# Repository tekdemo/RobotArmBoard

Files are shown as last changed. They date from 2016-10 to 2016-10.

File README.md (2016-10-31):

# Robot Arm Control Board

Teensy based control board designed for adding closed loop control to OWI-535 Robotic Arm Edge kit. 

## Setup

### Power
Using the 6 D cell battery output is suggested. See assembly notes for more details.

The Teensy is not powered by the batteries, and must be provided USB power for the robot to operate. 

### Motors

Each motor is driven by a pair of signal pins signals from the Teensy. Setting one `HIGH` and the other `LOW` will result in moving the motor, and thus each joint. 

- Pins `10` and `9` control `M1`, opening and closing the claw.
- Pins `6` and `5` control `M2`, the "wrist" joint
- Pins `4` and `3` control `M3`, the "elbow" joint. 
- Pins `20` and `21` control `M4`, the "shoulder" joint. 
- Pins `22` and `23` control `M5`, which rotates the arm 
- Pin `13` controls the light on the claw end. This is the same as the Teensy's built in LED.

### Analog Feedback

For closed loop feedback, the following pins are available:
- Pin `A1` corresponds to `M1`'s potentiometer. 
- Pin `A2` corresponds to `M2`'s potentiometer. 
- Pin `A3` corresponds to `M3`'s potentiometer. 
- Pin `A4` corresponds to `M4`'s potentiometer. 
- Pin `A5` corresponds to `M5`'s potentiometer. 

Note, each potentiometer "tuning" will be somewhat different, and require some setup for each robot and each joint. 

### Controller Input
The controller uses the same analog pins as the Analog feedback. As a result, it's not simple to use the controller for input when the analog feedback is plugged in. However, doing so will not harm the electronics. 

- Pin `A1` corresponds to `M1`'s joystick. 
- Pin `A2` corresponds to `M2`'s joystick. 
- Pin `A3` corresponds to `M3`'s joystick. 
- Pin `A4` corresponds to `M4`'s joystick. 
- Pin `A5` corresponds to `M5`'s joystick. 
- Pin `A0` corresponds to the Light slider. 

Due to the joystick construction the joystick will only generate a few values. When read using `AnalogRead`, you will get roughly `512` when the joystick is idle, and around `1023` or `0` when the joystick is pressed. 

The LED switch is wired up to it's own unique input, and can be used alongside a closed loop input without issue. The `LED` switch will be around `512` when off, and `1023` when on.

## Assembly

### Power Input

### Motors

### Controller Input Section

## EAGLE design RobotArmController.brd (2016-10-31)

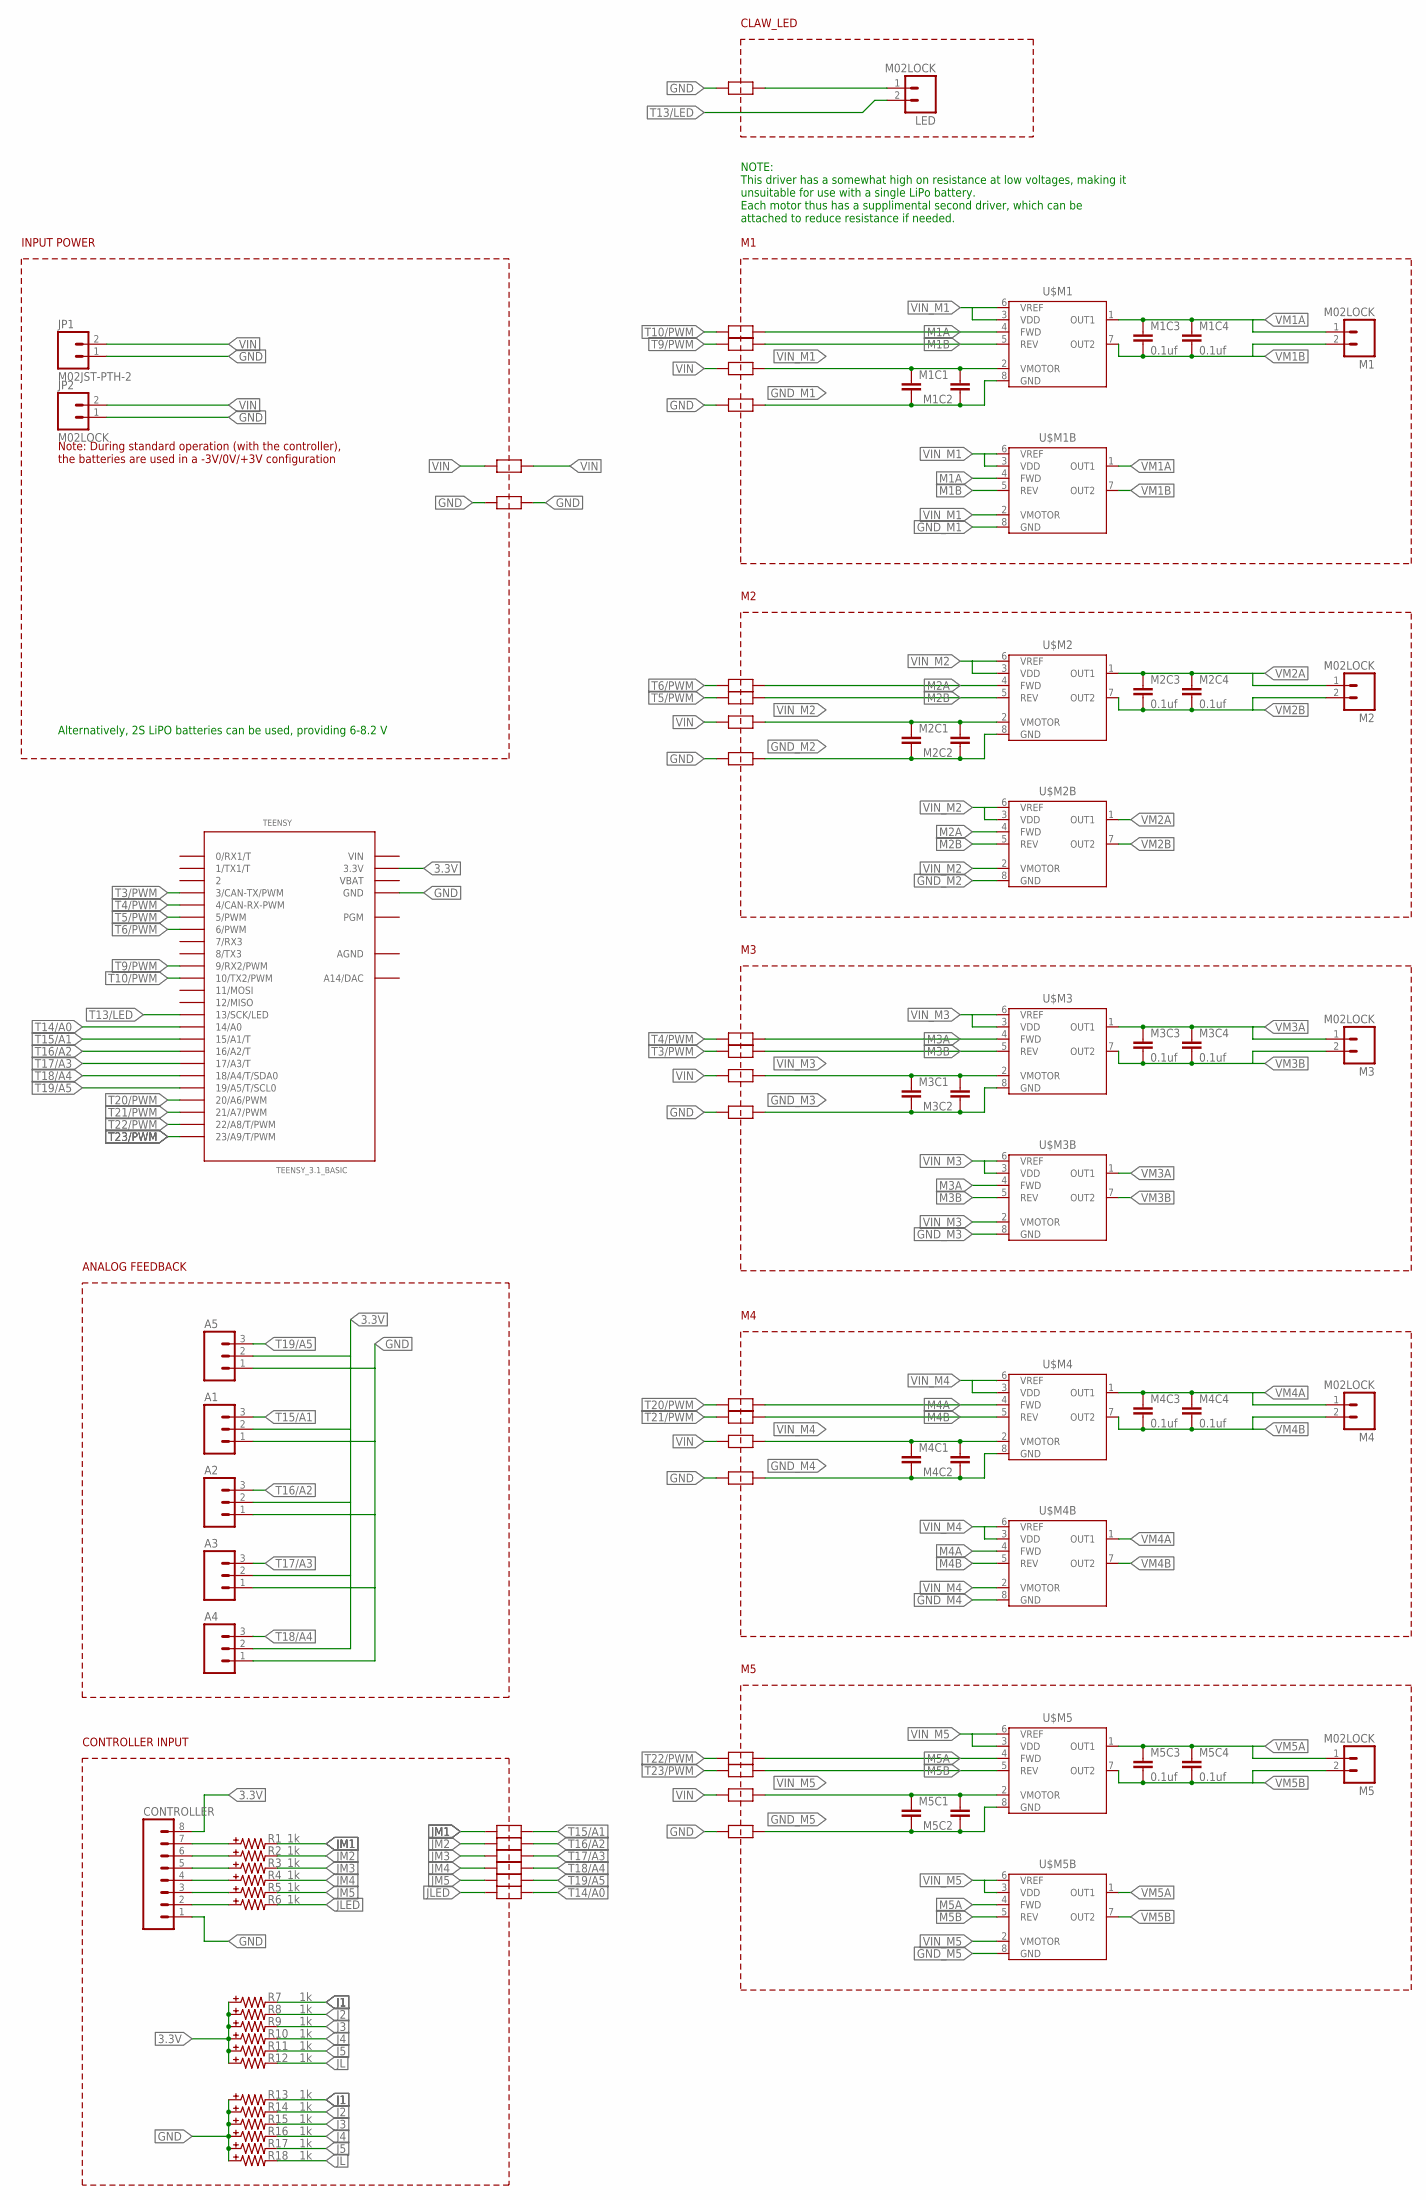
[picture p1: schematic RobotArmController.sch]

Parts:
A1, A2, A3, A4, A5: M03LOCK; 1X03_LOCK
CONTROLLER: M08LOCK; 1X08_LOCK
JP1: M02JST-PTH-2; JST-2-PTH
JP2: M02LOCK; 1X02_LOCK
LED: M02LOCK; 1X02_LOCK
M1, M2, M3, M4, M5: M02LOCK; 1X02_LOCK
M1C1, M2C1, M3C1, M4C1, M5C1: CAP1210; 1210
M1C2, M2C2, M3C2, M4C2, M5C2: CAPUNIVERSAL; 0402-0603-0805-UNIVERSAL
M1C3, M1C4, M2C3, M2C4, M3C3, M3C4, M4C3, M4C4, M5C3, M5C4: 0.1uf; 0402-0603-0805-UNIVERSAL
R1, R2, R3, R4, R5, R6, R7, R8, R9, R10, R11, R12, R13, R14, R15, R16, R17, R18: 1k; 0402-0603-0805-UNIVERSAL
TEENSY: TEENSY_3.1_BASIC
U$1, U$2, U$3, U$4, U$5, U$6, U$7, U$8, U$9, U$10, U$11, U$12, U$13, U$14, U$15, U$16, U$17, U$18, U$19, U$20, U$21, U$22, U$23, U$24, U$25, U$26, U$27, U$28, U$29: NET-JUNCTION-2
U$M1, U$M1B, U$M2, U$M2B, U$M3, U$M3B, U$M4, U$M4B, U$M5, U$M5B: ZXBM5210; SO08

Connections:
3.3V: A1.2, A2.2, A3.2, A4.2, A5.2, CONTROLLER.8, R7.+ (1), R8.+ (1), R9.+ (1), R10.+ (1), R11.+ (1), R12.+ (1), TEENSY.3.3V, TEENSY.3.3V1 (3.3V)
AGND: TEENSY.AGND
GND: A1.1, A2.1, A3.1, A4.1, A5.1, CONTROLLER.1, JP1.1, JP2.1, LED.1, R13.+ (1), R14.+ (1), R15.+ (1), R16.+ (1), R17.+ (1), R18.+ (1), TEENSY.GND, TEENSY.GND1 (GND), U$2.P$1, U$5.P$1, U$7.P$1, U$9.P$1, U$11.P$1, U$13.P$1, U$13.P$2, U$24.P$1, U$24.P$2
GND_M1: M1C1.2, M1C2.- (1), U$2.P$2, U$M1.8 (GND), U$M1B.8 (GND)
GND_M2: M2C1.2, M2C2.- (1), U$5.P$2, U$M2.8 (GND), U$M2B.8 (GND)
GND_M3: M3C1.2, M3C2.- (1), U$7.P$2, U$M3.8 (GND), U$M3B.8 (GND)
GND_M4: M4C1.2, M4C2.- (1), U$9.P$2, U$M4.8 (GND), U$M4B.8 (GND)
GND_M5: M5C1.2, M5C2.- (1), U$11.P$2, U$M5.8 (GND), U$M5B.8 (GND)
J1: CONTROLLER.7, R1.+ (1), R7.- (2), R13.- (2)
J2: CONTROLLER.6, R2.+ (1), R8.- (2), R14.- (2)
J3: CONTROLLER.5, R3.+ (1), R9.- (2), R15.- (2)
J4: CONTROLLER.4, R4.+ (1), R10.- (2), R16.- (2)
J5: CONTROLLER.3, R5.+ (1), R11.- (2), R17.- (2)
JL: CONTROLLER.2, R6.+ (1), R12.- (2), R18.- (2)
JLED: R6.- (2), U$29.P$1
JM1: R1.- (2), U$12.P$1
JM2: R2.- (2), U$25.P$1
JM3: R3.- (2), U$26.P$1
JM4: R4.- (2), U$27.P$1
JM5: R5.- (2), U$28.P$1
M1A: U$14.P$2, U$M1.4 (FWD), U$M1B.4 (FWD)
M1B: U$15.P$2, U$M1.5 (REV), U$M1B.5 (REV)
M2A: U$16.P$2, U$M2.4 (FWD), U$M2B.4 (FWD)
M2B: U$17.P$2, U$M2.5 (REV), U$M2B.5 (REV)
M3A: U$18.P$2, U$M3.4 (FWD), U$M3B.4 (FWD)
M3B: U$19.P$2, U$M3.5 (REV), U$M3B.5 (REV)
M4A: U$20.P$2, U$M4.4 (FWD), U$M4B.4 (FWD)
M4B: U$21.P$2, U$M4.5 (REV), U$M4B.5 (REV)
M5A: U$22.P$2, U$M5.4 (FWD), U$M5B.4 (FWD)
M5B: U$23.P$2, U$M5.5 (REV), U$M5B.5 (REV)
T3/PWM: TEENSY.3 (3/CAN-TX/PWM), U$19.P$1
T4/PWM: TEENSY.4 (4/CAN-RX-PWM), U$18.P$1
T5/PWM: TEENSY.5 (5/PWM), U$17.P$1
T6/PWM: TEENSY.6 (6/PWM), U$16.P$1
T9/PWM: TEENSY.9 (9/RX2/PWM), U$15.P$1
T10/PWM: TEENSY.10 (10/TX2/PWM), U$14.P$1
T13/LED: LED.2, TEENSY.13 (13/SCK/LED)
T14/A0: TEENSY.14/A0, U$29.P$2
T15/A1: A1.3, TEENSY.15/A1 (15/A1/T), U$12.P$2
T16/A2: A2.3, TEENSY.16/A2 (16/A2/T), U$25.P$2
T17/A3: A3.3, TEENSY.17/A3 (17/A3/T), U$26.P$2
T18/A4: A4.3, TEENSY.18/A4 (18/A4/T/SDA0), U$27.P$2
T19/A5: A5.3, TEENSY.19/A5 (19/A5/T/SCL0), U$28.P$2
T20/PWM: TEENSY.20/A6 (20/A6/PWM), U$20.P$1
T21/PWM: TEENSY.21/A7 (21/A7/PWM), U$21.P$1
T22/PWM: TEENSY.22/A8 (22/A8/T/PWM), U$22.P$1
T23/PWM: TEENSY.23/A9 (23/A9/T/PWM), U$23.P$1
VBAT: TEENSY.VBAT
VIN: JP1.2, JP2.2, TEENSY.VIN, U$1.P$1, U$3.P$1, U$4.P$1, U$4.P$2, U$6.P$1, U$8.P$1, U$10.P$1
VIN_M1: M1C1.1, M1C2.+ (2), U$1.P$2, U$M1.2 (VMOTOR), U$M1.3 (VDD), U$M1.6 (VREF), U$M1B.2 (VMOTOR), U$M1B.3 (VDD), U$M1B.6 (VREF)
VIN_M2: M2C1.1, M2C2.+ (2), U$3.P$2, U$M2.2 (VMOTOR), U$M2.3 (VDD), U$M2.6 (VREF), U$M2B.2 (VMOTOR), U$M2B.3 (VDD), U$M2B.6 (VREF)
VIN_M3: M3C1.1, M3C2.+ (2), U$6.P$2, U$M3.2 (VMOTOR), U$M3.3 (VDD), U$M3.6 (VREF), U$M3B.2 (VMOTOR), U$M3B.3 (VDD), U$M3B.6 (VREF)
VIN_M4: M4C1.1, M4C2.+ (2), U$8.P$2, U$M4.2 (VMOTOR), U$M4.3 (VDD), U$M4.6 (VREF), U$M4B.2 (VMOTOR), U$M4B.3 (VDD), U$M4B.6 (VREF)
VIN_M5: M5C1.1, M5C2.+ (2), U$10.P$2, U$M5.2 (VMOTOR), U$M5.3 (VDD), U$M5.6 (VREF), U$M5B.2 (VMOTOR), U$M5B.3 (VDD), U$M5B.6 (VREF)
VM1A: M1.1, M1C3.- (1), M1C4.- (1), U$M1.1 (OUT1), U$M1B.1 (OUT1)
VM1B: M1.2, M1C3.+ (2), M1C4.+ (2), U$M1.7 (OUT2), U$M1B.7 (OUT2)
VM2A: M2.1, M2C3.- (1), M2C4.- (1), U$M2.1 (OUT1), U$M2B.1 (OUT1)
VM2B: M2.2, M2C3.+ (2), M2C4.+ (2), U$M2.7 (OUT2), U$M2B.7 (OUT2)
VM3A: M3.1, M3C3.- (1), M3C4.- (1), U$M3.1 (OUT1), U$M3B.1 (OUT1)
VM3B: M3.2, M3C3.+ (2), M3C4.+ (2), U$M3.7 (OUT2), U$M3B.7 (OUT2)
VM4A: M4.1, M4C3.- (1), M4C4.- (1), U$M4.1 (OUT1), U$M4B.1 (OUT1)
VM4B: M4.2, M4C3.+ (2), M4C4.+ (2), U$M4.7 (OUT2), U$M4B.7 (OUT2)
VM5A: M5.1, M5C3.- (1), M5C4.- (1), U$M5.1 (OUT1), U$M5B.1 (OUT1)
VM5B: M5.2, M5C3.+ (2), M5C4.+ (2), U$M5.7 (OUT2), U$M5B.7 (OUT2)

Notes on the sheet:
INPUT POWER
Note: During standard operation (with the controller), the batteries are used in a -3V/0V/+3V configuration
Alternatively, 2S LiPO batteries can be used, providing 6-8.2 V
NOTE: This driver has a somewhat high on resistance at low voltages, making it unsuitable for use with a single LiPo battery. Each motor thus has a supplimental second driver, which can be attached to reduce resistance if needed.
CLAW_LED
ANALOG FEEDBACK
CONTROLLER INPUT

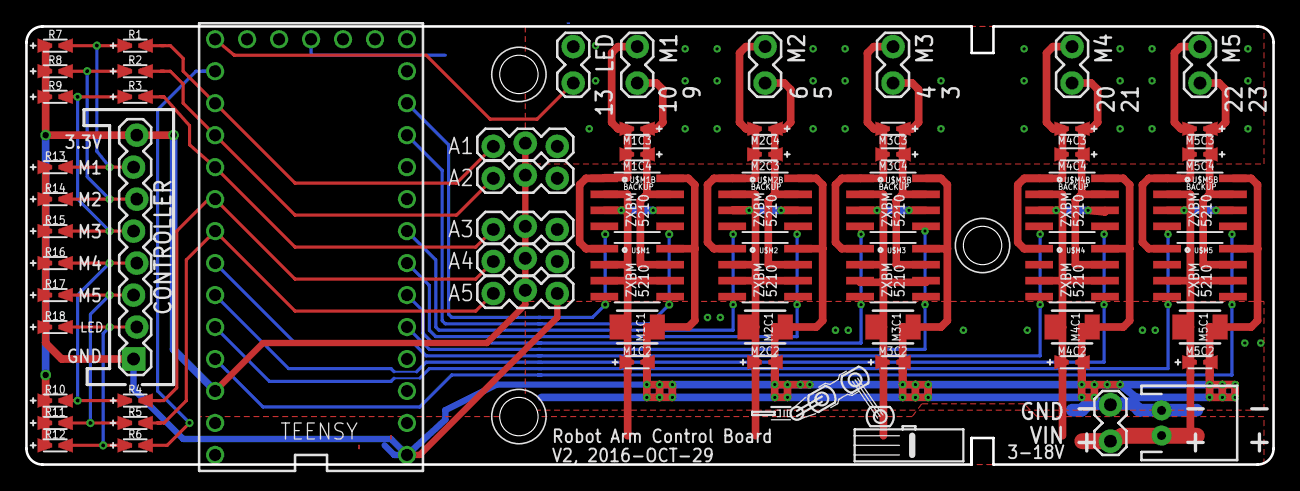
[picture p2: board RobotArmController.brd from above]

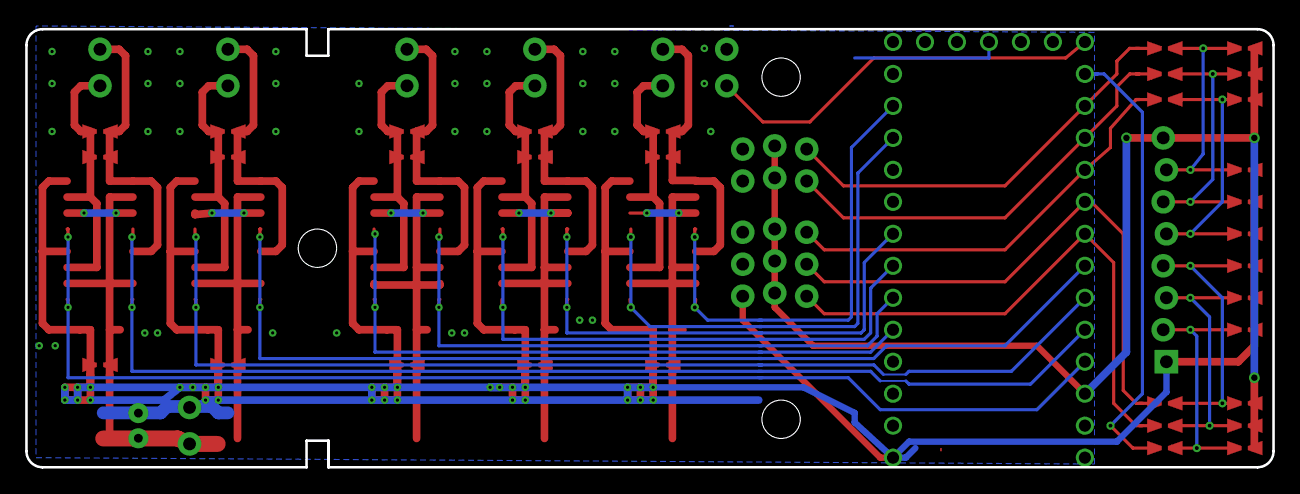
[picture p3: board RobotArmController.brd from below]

Board: 2 copper layers, 99.1 x 34.8 mm, 92 parts (12 on the bottom side), 62 nets.

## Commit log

2016-10-24 Draw schematic
    [RobotArmController.brd, RobotArmController.sch]
2016-10-24 Route motor drivers
    [RobotArmController.brd, RobotArmController.sch]
2016-10-24 Route + Define mechanical
    [RobotArmController.brd, RobotArmController.sch]
2016-10-24 Wire to teensy
    [RobotArmController.brd, RobotArmController.sch]
2016-10-24 Adjust for silkscreen and labels
    [RobotArmController.brd, RobotArmController.sch]
2016-10-29 Correct mounting slot errors
    [RobotArmController.brd]
2016-10-29 Remove LED resistor (not used)
    [RobotArmController.brd, RobotArmController.sch]
2016-10-29 Add OWI power connector, update gnd plane, silk
    [RobotArmController.brd, RobotArmController.sch]
2016-10-31 Add controller input
    [RobotArmController.brd, RobotArmController.sch]

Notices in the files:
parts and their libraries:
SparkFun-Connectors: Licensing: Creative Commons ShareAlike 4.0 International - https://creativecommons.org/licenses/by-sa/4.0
